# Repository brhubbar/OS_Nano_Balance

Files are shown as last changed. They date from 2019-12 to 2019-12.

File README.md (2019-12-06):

# OS_Nano_Balance
Firmware and design files for a digital mass balance with 3D printable components.
([Project Page](https://www.appropedia.org/3-D_Printable_Digital_Balance))

This balance is powered and controlled by an Arduino Nano. 
Using the digital I/O pins, the Nano powers and reads information from an HX711
32-bit load cell amplifier.
The readout from this loadcell can be calibrated using a standard mass.
Calibration mode is entered using a push button.
The calibrated value is distributed via two media: Serial and an LCD display.
When connected to the Nano over serial (115200 baud), the raw (tared) and calibrated 
readout are displayed.
Depending on the SSH client in use, this data can be logged and plotted -
primarily for scientific uses.
When an LCD is included in the system, the calibrated value is displayed with units.

**Power**

The entire system is powered by the USB input to the Nano.
This can be supplied by a computer or a 5V wall adapter.
* The HX711 and LCD are powered by digital I/O pins, meaning they can be independently turned on and off if desired.
* This works because the HX711 requires a maximum of 1.5 mA @ 5V (see data sheet in ``doc``).
* Similarly, the LCD requires around 2.5 mA @ 5V (see data sheet in ``doc``). 
* Arduino I/O pins can supply 40 mA @ 5V (recommended max is 20 mA continuous) 
(see [Arduino Forum](https://forum.arduino.cc/index.php?topic=121675.0)

## Wishlist
* Send a calibration value over serial, or offer a selection on the display (select with Tare)
* Improve readout on the display to offer more information and work with calibration
* Condense readout commands into functions to make the code 
[DRY](https://pragprog.com/the-pragmatic-programmer/extracts/tips)
* Improved averaging algorithm to improve Signal-to-Noise-Ratio
* Add compatibility for different types of displays
* Update readout resolution (number of decimals) to match the resolution of the load cell.
This could be adaptive baseed on the calibration value. 
(eg a 5000g load cell offers a different level of precision than a 50kg load cell).

## Printable Parts
The bed, base, and face are parametrically designed in FreeCAD.
Old designs created in OpenSCAD are available as well - 
these accommodate a TAL220 and TAL221 loadcell, but not an LCD.
These parts can be printed for a few dollars (depending on the cost of your filament).
If you are using an LCD, check the dimensions on ``Face.FCStd`` before printing.

## Wiring
Wiring has not yet been cleanly drawn up. 
The LCD wiring is based on the 
[Hello World](https://www.arduino.cc/en/Tutorial/HelloWorld)
example.
Pin locations can be determined by looking at the .ino source code.

**Load Cell --> HX711:**  
* red --> E+  
* blk --> E-  
* grn --> A+  
* wht --> A-  

**HX711 --> Arduino:**  
The HX711 is powered by the Arduino's digital pin. 
This is possible because the Arduino can supply 20 mA of current, while the 
HX711 only requires 1.5 mA. 
* GND --> GND  
* DT  --> D2  
* SCK --> D3  
* VCC --> D4  

**Buttons --> Arduino:**  
* GND --> Cal  --> D7
* GND --> Tare --> D8

## Firmware
The firmware sends a readout to the Serial Monitor for interaction.
Arduino's Serial Plotter can be used to get a live readout of changing mass on
the balance.

### Tare
To tare, simply hit the tare button (on pin 8). This will zero the output.

### Calibrate
To calibrate, hit the calibrate button (on pin 7). 
This will send the scale into its calibrate state.
You may tare the scale while in calibration state.
The scale will take several averages and then calculate a new sensitivity.
At this time, the device is set to calibrate with 0.2359 kg, the mass of 1 US Cup of water.

## Data Logging
To log data, use a third-party client such as PuTTY, which offers session-logging
capabilities.

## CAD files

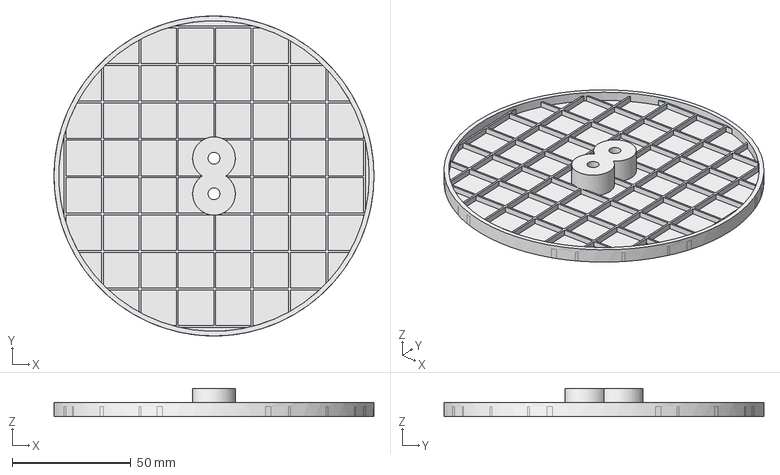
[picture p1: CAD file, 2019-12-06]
cad/Bed.FCStd
135.0 x 135.0 x 12.0 mm

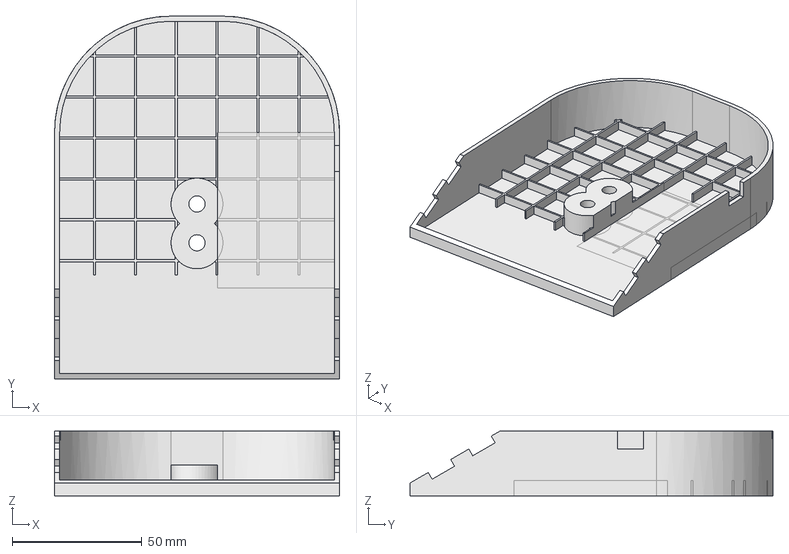
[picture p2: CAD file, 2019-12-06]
cad/Base.FCStd
110.0 x 140.0 x 25.0 mm

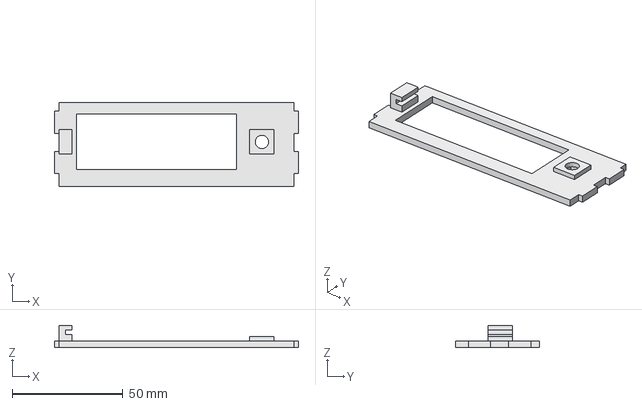
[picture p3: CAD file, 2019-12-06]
cad/Face.FCStd
110.0 x 37.7 x 10.0 mm

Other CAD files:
cad/OpenSCAD/Base.scad
cad/OpenSCAD/Bed.scad
cad/OpenSCAD/Cover.scad
cad/OpenSCAD/LoadCellRx.scad
cad/OpenSCAD/TAL220.scad
cad/OpenSCAD/TAL221.scad
cad/OpenSCAD/snap_joint.scad

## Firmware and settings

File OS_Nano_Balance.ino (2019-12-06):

/*  OS Nano Balance uses a load cell to measure and report an object's mass.
    Copyright (C) 2019 Benjamin Hubbard

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
    You should have received a copy of the GNU General Public License
    along with this program.  If not, see <https://www.gnu.org/licenses/>.
*/

/* External Libraries */
// Load cell amplifier.
#include "src\HX711\src\HX711.h"
// Hard Memory read/write.
#include <EEPROM.h>
// LCD Controller.
#include "src\LiquidCrystal\src\LiquidCrystal.h"

/* Globals */
// HX711
// Data pin.
const int hx_dt  = 2;
// Clock pin.
const int hx_sck = 3;
// Vcc pin - HX711 requires 3-5V @ 1.5 mA, Nano supplies 5V @ 20 mA.
const int hx_vcc = 4;
// Number of averages while measuring. *Set to 1 because the library's averaging
// is too slow and interferes with other interactions.
const int hx_num_avgs = 1;
// Number of averages while calibrating.
const int hx_cal_num_avgs = 10;
// HX711 object.
HX711 loadcell;

// LCD
// Is there an LCD?
bool isLCD = true;
// Reset pin.
const int lcd_rs = A0;
// Enable pin.
const int lcd_en = A1;
// Data pins.
const int lcd_d4 = A2;
const int lcd_d5 = A3;
const int lcd_d6 = A4;
const int lcd_d7 = A5;
// Display size.
const int lcd_rows = 2;
const int lcd_cols = 16;
// Power supply. allaboutcircuits.com suggests an LCD requires 5V @ 3mA.
const int lcd_vcc = 5;
// LCD object.
LiquidCrystal lcd(lcd_rs, lcd_en, lcd_d4, lcd_d5, lcd_d6, lcd_d7);

// Calibration (EEPROM).
// Signature to store in the memory when calibrating.
char cal_sig = 'C';
// Variable to store calibration signature check.
char cal_check;
// Address of calibration signature.
int cal_sig_addr = 0;
// Address of the stored calibration value.
int cal_val_addr = sizeof(char);
// Stores the calibration value from EEPROM.
float cal_val = 0.00f;
// Mass used to calibrate (1 US cup of water);
double standard_mass = 0.2359;
// Mass units.
String units = "kg";
// Sensitivity value.
float sensitivity;


// Input pins.
// Calibrate.
const int btn_cal = 7;
// Tare.
const int btn_tare = 8;


// Readouts.
// Raw value.
double val;
// Scaled value.
float mass;
// Number of digits after the decimal.
int num_digits = 6;


/* Methods */
/* initLoadCell() 
 * Set up the HX711 for use. Turns on the device, then verifies the calibration 
 * value.
 */
HX711 initLoadCell() {
	Serial.println("Initializing HX711...");
	
	// Turn on the HX711 power supply.
	pinMode(hx_vcc, OUTPUT);
	digitalWrite(hx_vcc, HIGH);
	
	// Give it time to power on.
	delay(500);
	
	// Initialize the HX711.
	HX711 loadcell;
	loadcell.begin(hx_dt, hx_sck);
	
	// Wait until it's ready.
	bool is_ready = false;
	int num_retries = 3;
	int wait_delay = 200;
	while (!is_ready) {
		// Give some indication that it's thinking.
		Serial.print("...");
		is_ready = loadcell.wait_ready_retry(num_retries, wait_delay);
	}
	
	Serial.println("HX711 Initialized!");
	
	// Set calibration value.
	// Check if the calibration has been saved.
	Serial.println("Loading calibration...");
	EEPROM.get(cal_sig_addr, cal_check);
	if (cal_check == cal_sig) {
		// Get the saved calibration value.
		EEPROM.get(cal_val_addr, cal_val);
		Serial.print("Calibration value: ");
		Serial.print(cal_val);
		Serial.print(" div/");
		Serial.println(units);
		
		// Apply the calibration value to the driver.
		loadcell.set_scale(cal_val);
	} else {
		// There is not a stored calibration value.
		Serial.println("Calibration value is not stored.");
		Serial.println("Defaulting to calibration of 1 (raw value)");
		loadcell.set_scale(1.00f);
	}

	// Give the HX711 a chance to finish initializing.
	delay(500);
	
	// Tare the thing.
	Serial.println("Tare...");
	loadcell.tare(hx_num_avgs);
	
	return loadcell;
}


// calibrate() calibrates the load cell.
// loadcell = load cell amplifier object.
// standard_mass = mass used to calibrate.
// units = units to display in the readout. 
void calibrate() {	
	// Give the user a second to release the button.
	delay(1000);
		
	// Recall that the buttons are active LOW.
	// Start reading, wait until a button press indicates calibration is done.
	while (digitalRead(btn_cal) == 1) {
		if (digitalRead(btn_tare) == 0) {
			// TODO: Make a custom tare function to keep this DRY.
			Serial.println("Tare...");
			loadcell.tare(hx_num_avgs);
		}
		
		// Read the tared value (raw reading).
		val = loadcell.get_value(hx_cal_num_avgs);
		Serial.print("Raw Value: ");
		Serial.print(val);
		
		// Calculate the sensitivity.
		sensitivity = (float) (val / standard_mass);
			
		// Let the user know what they can now set it to.
		Serial.print(", new sensitivity: ");
		Serial.print(sensitivity, num_digits);
		Serial.print(" div/");
		Serial.print(units);
	}	// Button pressed.
	
	// Set the sensitivity.
	// TODO: Make a print_with_units function.
	Serial.print("Using sensitivity: ");
	Serial.print(sensitivity, num_digits);
	Serial.print(" div/");
	Serial.println(units);
	loadcell.set_scale(sensitivity);
	
	// Store the sensitivity to hard memory.
	EEPROM.put(cal_sig_addr, cal_sig);
	EEPROM.put(cal_val_addr, sensitivity);
	
	// Give the user a chance to release the button.
	delay(500);
	return;
}


/* initDisplay()
 * Prepare the LCD for use. Turns on the display and preps initial settings.
 */
LiquidCrystal initLCD() {
	Serial.println("Initializing LCD...");
	
	// Turn on the LCD power supply.
	pinMode(lcd_vcc, OUTPUT);
	digitalWrite(lcd_vcc, HIGH);
	
	// Give it time to power on.
	delay(500);
	
	// Initialize the display.
	lcd.begin(lcd_cols, lcd_rows);
	// Clear the display.
	lcd.clear();
	// Home the cursor.
	lcd.home();
	// Hide the cursor.
	lcd.noCursor();
	// Ensure the display is on. (lcd.noDisplay() turns off the display).
	lcd.display();
	
	// Test the display.
	Serial.println("Testing the display...");
	// Print an 8 to each character in the display.
	for (int i = 0; i < lcd_rows * lcd_cols; i++) {
		lcd.print("8");
		delay(50);
	}
	delay(1000);
	lcd.clear();
	//lcd.home();
	
	Serial.println("LCD initialized!");
	
	return lcd;
}


void setup() {
	Serial.begin(115200);
	while(!Serial){
		// Wait for serial to initialize.
	}	// Serial initialized.
	
	::loadcell = initLoadCell();
	if (isLCD) {
		initLCD();
	}
	
	/* Tare and Calibarion sensors. Internal pullup resistor defaults the pin to 
	 * HIGH, meaning the tare must be connected to ground when closed/active.
	 */
	pinMode(::btn_cal, INPUT_PULLUP);
	pinMode(::btn_tare, INPUT_PULLUP);
}


void loop() {
	/* TODO: make a custom running average algorithm - using the built in averages
	 * introduces too much delay and making detection of button presses difficult.
	 */
	// See what's being measured without the calibration (but with tare offset).
	val = loadcell.get_value(hx_num_avgs);
	// Calibrated measurement.
	mass = loadcell.get_units(hx_num_avgs);
	
	// Report the measurements.
	Serial.print("Raw value: ");
	Serial.print(val);
	Serial.print(", Mass: ");
	Serial.print(mass, num_digits);
	Serial.print(" ");
	Serial.println(units);
	lcd.clear();
	lcd.home();
	lcd.print(mass, num_digits);
	lcd.print(" ");
	lcd.print(units);
	
	// Watch for a tare request.
	if (digitalRead(btn_tare) == 0) {
		Serial.println("Tare...");
		loadcell.tare(hx_num_avgs);
	}
		
	// Watch for a calibration request.
	if (digitalRead(btn_cal) == 0) {
		Serial.println("Calibrate...");
		calibrate();
	}
}

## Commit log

2019-11-07 Adds OpenSCAD files.
    [Base.scad, Bed.scad, Cover.scad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]
2019-11-22 Relocates OpenSCAD files for safekeeping
    [Base.scad, Bed.scad, Cover.scad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]
2019-11-22 Translates base design into FreeCAD (with design changes).
    [Base.FCStd]
2019-11-22 Adds Parameters.csv
    [Parameters.csv]
2019-11-22 Adds Bed - first iteration with grid. Increases standoff height on base from 7.5mm to 10mm
    [Base.FCStd, Bed.FCStd]
2019-11-22 Adds grid to Base; makes LCD a snap on to improve printability and make the screen optional. Cleans up parameters in Bed.
    [Base.FCStd, Bed.FCStd]
2019-12-04 Finalize bed and base cad. * Adds slot in grid for PCB in base. Assumes a PCB that is 45x60mm. * Moves USB slot to account for female header height.
    [Base.FCStd, Bed.FCStd]
2019-12-05 Updates parameters.csv and adds Face (w/ and w/o LCD cutout). Lessons Learned: - FreeCAD just use one file for all parts (to share parameters). Can export a single body/part at a time.
    [Face.FCStd, Parameters.csv]
2019-12-05 Corrects syntax errors and completes deployability. LiquidCrystal must be initialized (cannot be declared...) Moves lcd_vcc Commented out a line that for some reason made the code compile.
    [OS_Nano_Balance.ino]

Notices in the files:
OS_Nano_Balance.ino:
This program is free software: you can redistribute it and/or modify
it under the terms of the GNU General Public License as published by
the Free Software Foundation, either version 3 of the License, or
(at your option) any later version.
